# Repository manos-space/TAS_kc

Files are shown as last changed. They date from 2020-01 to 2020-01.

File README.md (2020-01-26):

### Two-Axis Sculpt Keycaps

#### Renders:
TAS_profile_3x6_render
TAS_profile_3x6_render2
TAS_profile_5x6_render1
TAS_profile_ergo_render

#### Production:
* The recommended method for 3D printing these keycaps is stereolithography (SLA), selective laser sintering is also a valid method but results in more grainy texture and less consistent dimensions. Filament deposition printing (FDM) can also be used but keycap stem fitment may be compromised, more discussion on this in the design notes section

* Currently supported printing methods:
    * Selective Laser Sintering (SLS): **Supported**
        * Individual keycap models in `./keycaps/sls/stl`
        * Layouts in `./layouts/sls/stl`

    * Stereolithography (SLA): **Supported**
        * Individual keycap models in `./keycaps/sla/stl`
        * Layouts for an Anycubic Photon SLA printer in `./layouts/sla/photon_layouts`

    * Filament Deposition Printing (FDM): **Not yet supported**

----

##### SLA Printing:
* The keycaps can be printed individually, or by arranging selected keycap models in slicing software, such as [Prusa Slicer](https://www.prusa3d.com/prusaslicer/)
    * The layout of keycaps for SLA will vary depending on the printer being used, as consumer-tier printers are limited in the quantity of keycaps being printed at once due to build plate area as well as model cross-sectional area being printed at one time
        * I recommend downloading individual keycap models and arranging them to suit the SLA printer being used
* If using a printer similar to the Anycubic Photon, I suggest creating a checker board pattern to minimize the chance of failed prints
    * The STL files in the `./layouts/SLA/photon_layouts` are what I use to print sets of these keycaps:
    prusa_slicer_layout

* Print Settings

    * If using Elegoo Black Resin, the following settings result in successful prints:
        - 0.03 mm layer height
        - 8 bottom layers
        - 90 second bottom exposure time
        - 15 second normal exposure time
        - 1.5 second off time
        - 65F / 18.33C ambient temperature

----

##### SLS Printing: 
* Keycap layouts can be sent to a 3D printing service such as [3D Hubs](https://www.3dhubs.com/) and made with SLS Nylon

----

#### Supported layouts:
##### Planck:
planck_layout_render
* SLS: Can be made by printing the `./layouts/stl/TAS_profile_layout_4x6_a.stl` and `./layouts/stl/TAS_profile_layout_4x6_b.stl` layout files

##### Preonic:
preonic_layout_render
* SLS: Can be made by printing the `./layouts/stl/TAS_profile_layout_5x6_a.stl` and `./layouts/stl/TAS_profile_layout_5x6_b.stl` layout files

##### Corne
corne_layout_render
* SLS: Can be produced by printing out two copies of the `./layouts/stl/TAS_profile_layout_4x6_c.stl` file

----

#### Design notes:

* The keycaps are directly modelled in Solidworks, parametric modelling would be a more precise approach

* The base set of TAS-profile keycaps consists of 3 rows and 4 columns
    * The C0 column has only 1 axis of sculpt (x axis), like a typical set of sculpted SA-profile keycaps
    * Columns C1-C3 are sculpted in two axes (x and y axes), scooping up towards the outer/C3 column, and down towards the home/R1 row

3x4_base_set

* 3x5, 3x6, 4x5, 4x6... etc. layouts can be made by mirroring the caps with the "C0" column as the mirror axis
    * A 5 row layout is possible by using the `./keycaps/stl/rn` number row models

3x6_set

* The bottom row (R3) leaves room for customization, depending on the keyboard they will be used on
* The bottom row I decided to use consists of keycaps from the home/R1 row, as is typical with SA-profile keycaps along with a 1.25 unit thumb key as seen on keyboards like the [Corne](https://github.com/foostan/crkbd)

4x6_set

* The models' stem slots are sized differently for SLA and SLS printing:
    * SLS models have narrower stem slots: 1.17 mm, which should result in a snug fit
    * SLA models have more detailed stem slots and are larger: 1.325/1.425mm
        * Tested on Kailh Box and Pro Heavy stems

sls_stem_dimensions
sla_stem_dimensions

* The geometry of the keycap is defined using the following parameters:
    1) Base square side length
    2) Top plane center height
    3) Top square side length
    4) Vertex length (2+ vertices need to be defined)
    5) Sculpt depth
    6) Vertex tapered fillet radii

parameters_legend

tapered_fillet_radii_legend

* Some parameters are held constant for the keycaps, these are the parameter values I used for my set:
    * Base square side length = 18.50mm
    * Top square side length = 12.50mm
        * **Note**: This is true for 1 unit (square) keycaps, 1.25+ unit sized keycaps have a rectangular top/bottom "square" and these parameters need to be multiplied by a factor depending on the size
            * e.g.: 1.25 unit keycaps have dimensions  18.50mm x 1.25(18.50mm) for the base rectangle side length and 12.50mm x 1.25(12.50mm) for the top rectangle side length
    * Sculpt depth = 0.80mm
        * This is set to 1.0mm for the keycaps in the place of "F" and "J" on a QWERTY layout
    * Vertex tapered fillet radius 1 = 2.00mm
    * Vertex tapered fillet radius 2 = 0.50mm

----

### To-do:

----
###### Models were created in Solidworks, then exported as STL. Feel free to use/modify/redistribute.

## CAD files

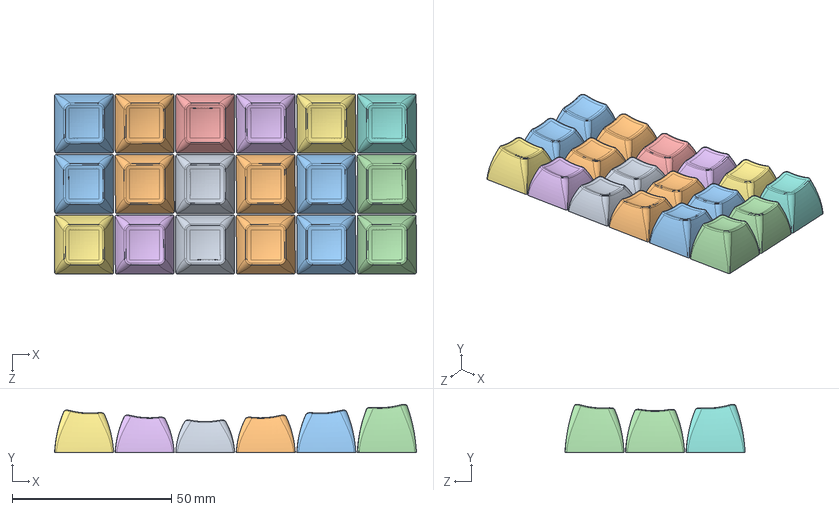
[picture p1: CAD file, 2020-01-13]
layouts/SLS/sldasm/TAS_profile_layout_3x6.SLDASM
113.6 x 15.1 x 56.6 mm
r1_c0
r1_c1 x 2
r1_c2 x 2
r1_c3
r0_c0
r0_c1 x 2
r0_c2 x 2
r0_c3
r2_c0
r2_c1 x 2
r2_c2 x 2
r2_c3

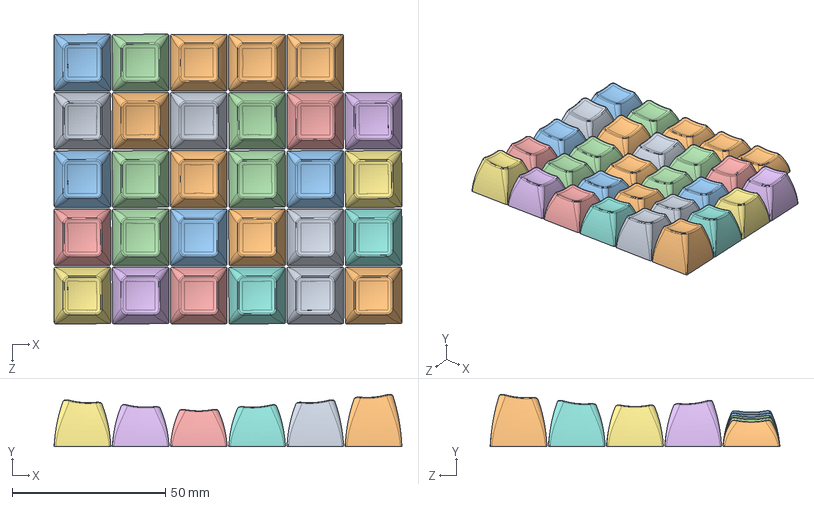
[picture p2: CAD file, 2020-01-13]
layouts/SLS/sldasm/TAS_profile_layout_5x6_b.SLDASM
113.6 x 17.1 x 94.6 mm
r0_c0
r1_c0 x 4
r2_c0
r0_c1 x 2
r0_c2 x 2
r0_c3
r1_c3
r2_c3
r2_c2 x 2
r2_c1 x 2
r1_c2 x 3
r1_c1 x 3
rn_c0
rn_c1
rn_c2
rn_c1_mirrored
rn_c2_mirrored
rn_c3_mirrored

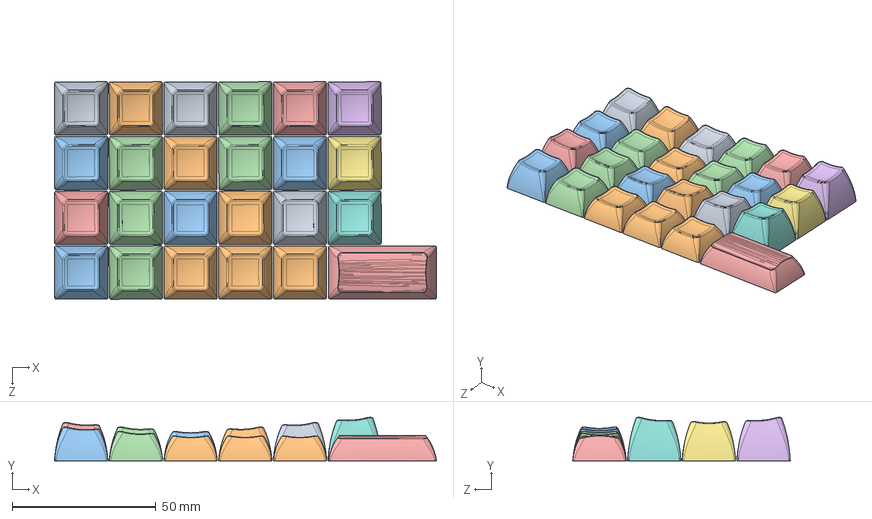
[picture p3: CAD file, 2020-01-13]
layouts/SLS/sldasm/TAS_profile_layout_4x6_a.SLDASM
132.7 x 15.1 x 75.6 mm
r0_c0
r1_c0 x 4
r2_c0
r0_c1 x 2
r0_c2 x 2
r0_c3
r1_c3
r2_c3
r2_c2 x 2
r2_c1 x 2
r1_c2 x 3
r1_c1 x 3
r3_2u

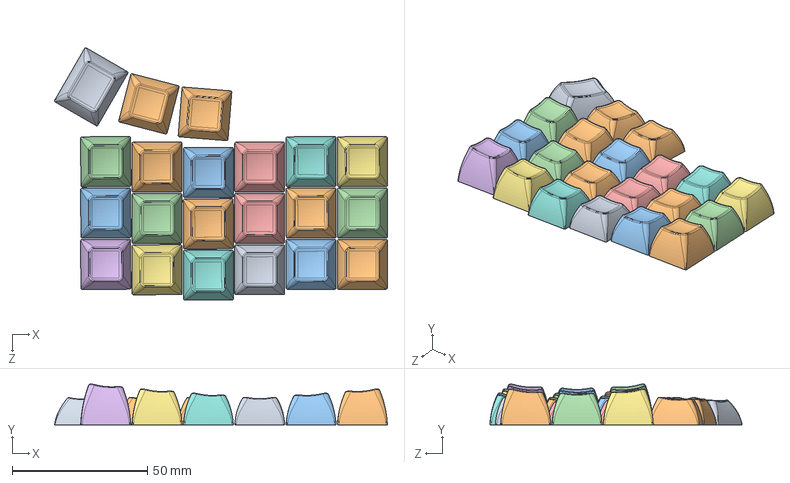
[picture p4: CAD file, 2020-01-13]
layouts/SLS/sldasm/TAS_profile_layout_4x6_corne_a.SLDASM
123.2 x 15.1 x 93.4 mm
r3-1.25u
r1_c1 x 4
r1_c3
r1_c2 x 2
r1_c0
r0_c3
r0_c2 x 2
r0_c1 x 2
r0_c0
r2_c2 x 2
r2_c1 x 2
r2_c3
r2_c0

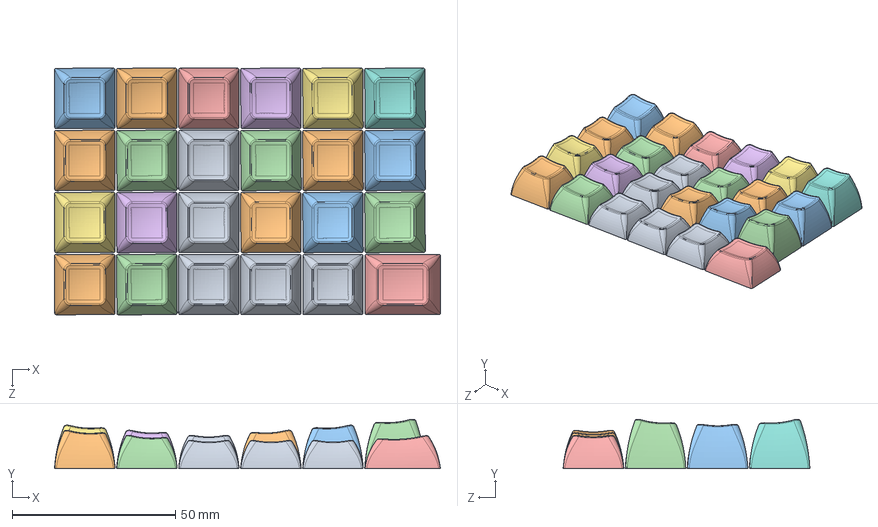
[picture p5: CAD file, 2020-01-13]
layouts/SLS/sldasm/TAS_profile_layout_4x6_c.SLDASM
118.2 x 15.1 x 75.6 mm
r1_c0 x 4
r1_c2 x 3
r1_c3
r1_c1 x 3
r0_c0
r0_c1 x 2
r0_c2 x 2
r0_c3
r2_c0
r2_c1 x 2
r2_c2 x 2
r2_c3
r3-1.25u

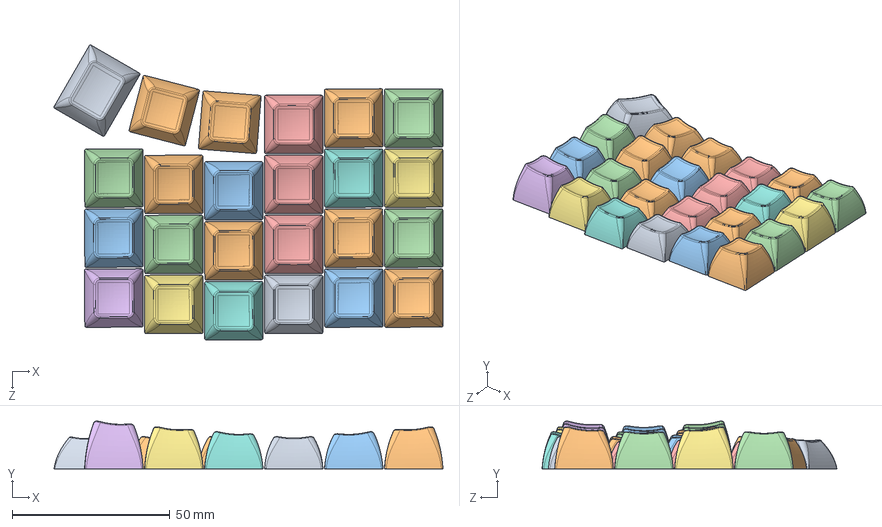
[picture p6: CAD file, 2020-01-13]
layouts/SLS/sldasm/TAS_profile_layout_4x6_ergo.SLDASM
123.2 x 15.1 x 93.4 mm
r3-1.25u
r1_c1 x 5
r1_c3
r1_c2 x 3
r1_c0 x 2
r0_c3
r0_c2 x 2
r0_c1 x 2
r0_c0
r2_c2 x 2
r2_c1 x 2
r2_c3
r2_c0

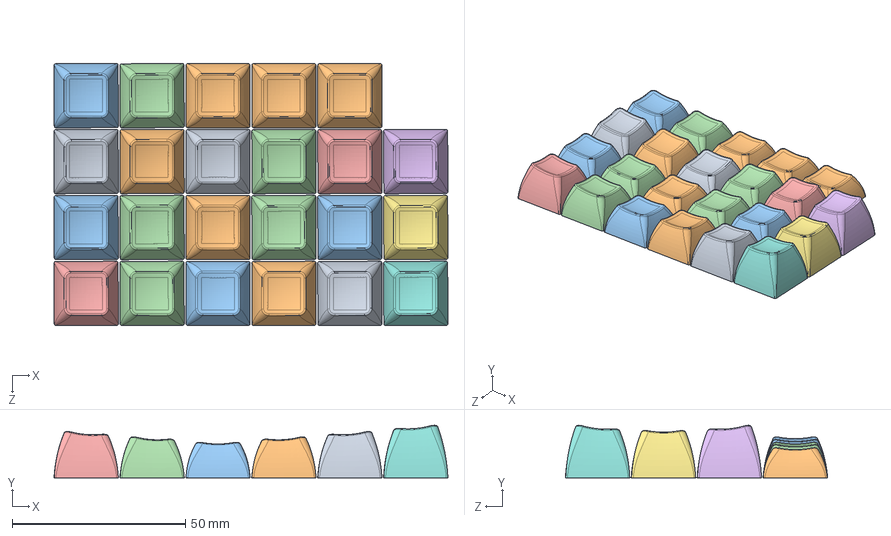
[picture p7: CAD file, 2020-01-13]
layouts/SLS/sldasm/TAS_profile_layout_4x6_b.SLDASM
113.6 x 15.1 x 75.6 mm
r0_c0
r1_c0 x 4
r2_c0
r0_c1 x 2
r0_c2 x 2
r0_c3
r1_c3
r2_c3
r2_c2 x 2
r2_c1 x 2
r1_c2 x 3
r1_c1 x 3

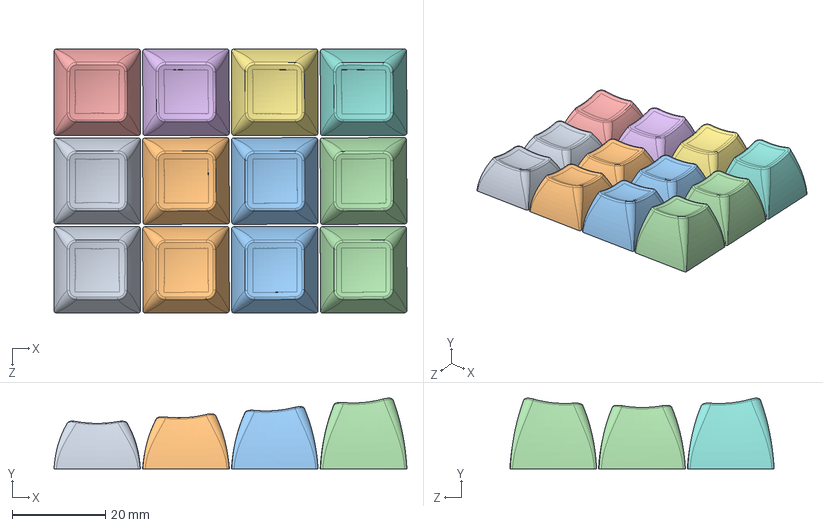
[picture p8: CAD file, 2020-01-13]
layouts/SLS/sldasm/TAS_profile_layout_3x4.SLDASM
75.6 x 15.1 x 56.6 mm
r1_c0
r1_c1
r1_c2
r1_c3
r0_c0
r0_c1
r0_c2
r0_c3
r2_c0
r2_c1
r2_c2
r2_c3

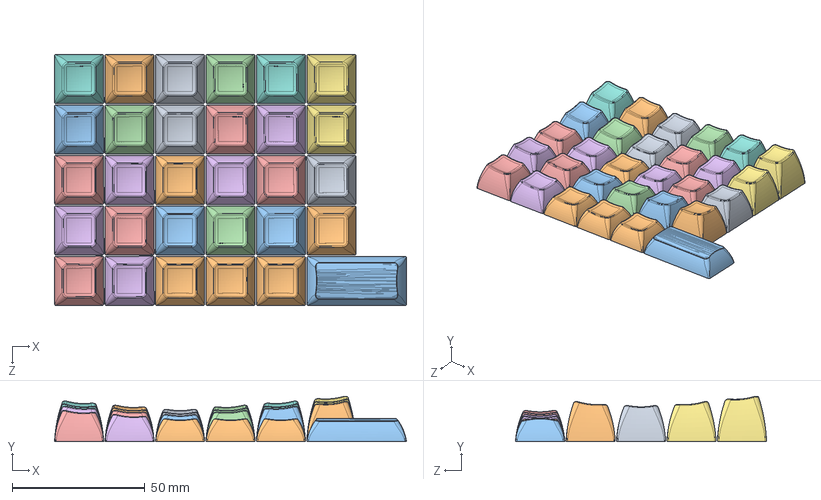
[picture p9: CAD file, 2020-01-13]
layouts/SLS/sldasm/TAS_profile_layout_5x6_a.SLDASM
132.6 x 17.1 x 94.6 mm
r0_c0
r1_c0 x 4
r2_c0
rn_c1
r0_c1 x 2
r0_c2 x 2
r0_c3
rn_c2
r1_c3
r2_c3
r2_c2 x 2
r2_c1 x 2
r1_c2 x 3
r1_c1 x 3
rn_c3
rn_c2_mirrored
rn_c0
rn_c1_mirrored
r3_2u

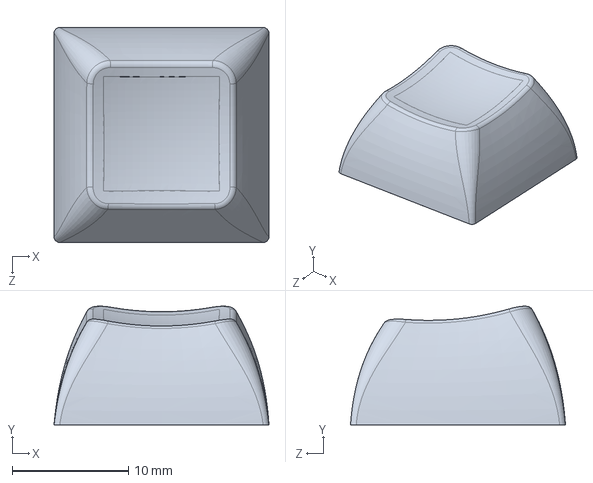
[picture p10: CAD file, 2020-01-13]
keycaps/SLS/sldprt/r0/r0_c0.SLDPRT
18.5 x 10.2 x 18.5 mm

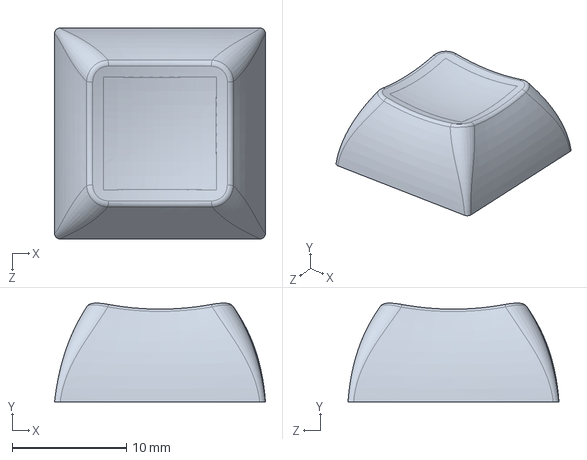
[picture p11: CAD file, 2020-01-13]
keycaps/SLS/sldprt/r1/r1_c0.SLDPRT
18.5 x 8.66 x 18.5 mm

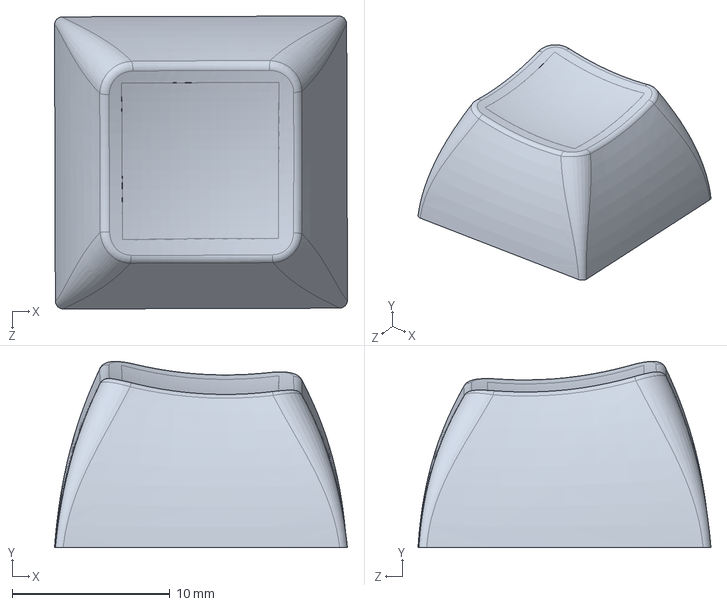
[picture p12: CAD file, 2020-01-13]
keycaps/SLS/sldprt/r2/r2_c1.SLDPRT
18.6 x 11.8 x 18.6 mm

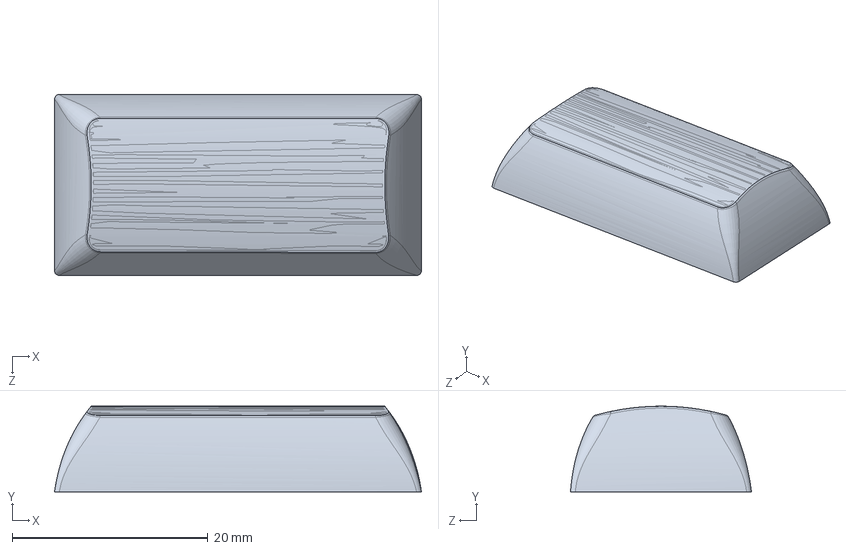
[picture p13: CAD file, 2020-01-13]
keycaps/SLS/sldprt/r3/r3_2u.SLDPRT
37.5 x 8.75 x 18.5 mm

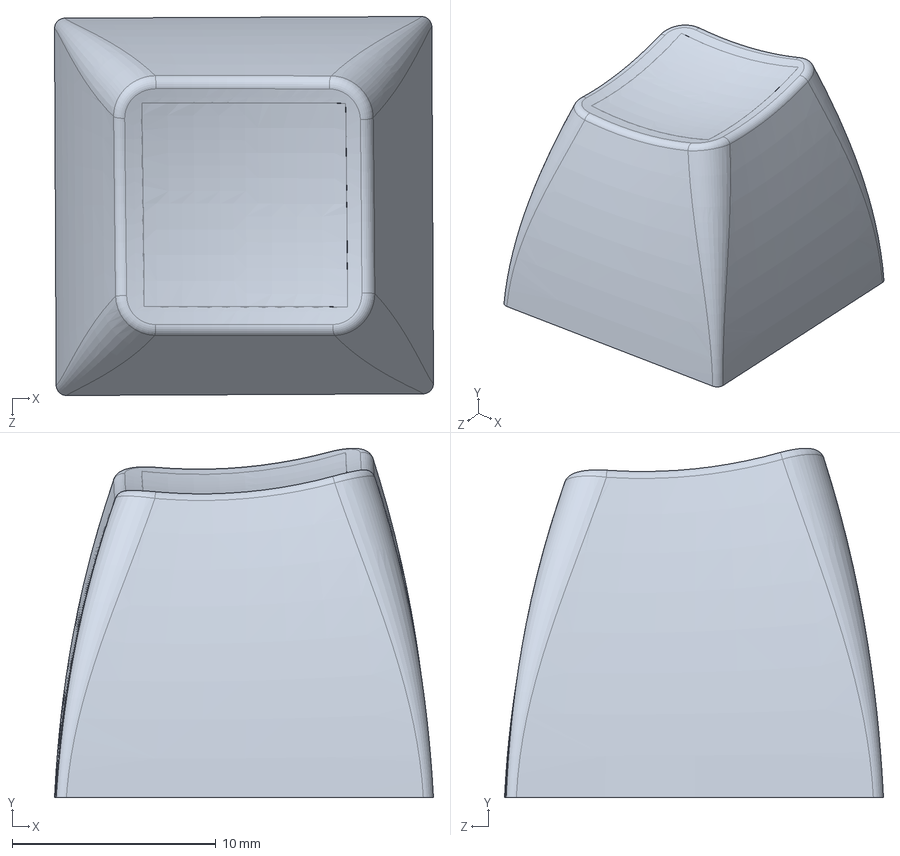
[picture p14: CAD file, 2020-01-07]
keycaps/SLS/sldprt/rn/rn_c3.SLDPRT
18.6 x 17.1 x 18.6 mm

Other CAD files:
layouts/SLS/sldasm/TAS_profile_layout_4x6_corne_b.SLDASM
keycaps/SLS/sldprt/r0/r0_c3.SLDPRT
keycaps/SLS/sldprt/r1/r1_c1.SLDPRT
keycaps/SLS/sldprt/r2/r2_c3.SLDPRT
keycaps/SLS/sldprt/r0/r0_c1.SLDPRT
keycaps/SLS/sldprt/r0/r0_c2.SLDPRT
keycaps/SLS/sldprt/r1/r1_c2.SLDPRT
keycaps/SLS/sldprt/r1/r1_c3.SLDPRT
keycaps/SLS/sldprt/r2/r2_c0.SLDPRT
keycaps/SLS/sldprt/r2/r2_c2.SLDPRT
keycaps/SLS/sldprt/r3/r3-1.25u.SLDPRT
keycaps/SLS/sldprt/rn/rn_c0.SLDPRT
keycaps/SLS/sldprt/rn/rn_c1.SLDPRT
keycaps/SLS/sldprt/rn/rn_c1_mirrored.SLDPRT
keycaps/SLS/sldprt/rn/rn_c2.SLDPRT
keycaps/SLS/sldprt/rn/rn_c2_mirrored.SLDPRT
keycaps/SLS/stl/r0/r0_c0.STL
keycaps/SLS/stl/r0/r0_c1.STL
keycaps/SLS/stl/r0/r0_c2.STL
keycaps/SLS/stl/r0/r0_c3.STL
keycaps/SLS/stl/r1/r1_c0.STL
keycaps/SLS/stl/r1/r1_c1.STL
keycaps/SLS/stl/r1/r1_c2.STL
keycaps/SLS/stl/r1/r1_c3.STL
keycaps/SLS/stl/r2/r2_c0.STL
keycaps/SLS/stl/r2/r2_c1.STL
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

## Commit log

2020-01-07 added num row keycap models
    [rn_c0.SLDPRT, rn_c0.STL, rn_c1.SLDPRT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]
2020-01-13 create SLS/SLA process file subdirs
    [TAS_profile_layout_3x4.SLDASM, TAS_profile_layout_3x4.SLDPRT, TAS_profile_layout_3x6.SLDASM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]
2020-01-13 updated layouts to 1.5mm thick keycap models
    [TAS_profile_layout_3x4.SLDASM, TAS_profile_layout_3x4.SLDPRT, TAS_profile_layout_3x6.SLDASM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]
2020-01-22 removed unused keycap models
    [r0_c4.SLDPRT, r0_c4.STL, r1_c4.SLDPRT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]
